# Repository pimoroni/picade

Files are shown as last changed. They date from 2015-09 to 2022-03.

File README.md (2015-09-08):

Picade
======

**This repository is for the Kickstarter Picade PCB, for the newer retail Picade please see: https://github.com/pimoroni/picade-sketch**

All Picade related designs and documents.

- **eagle**: contains the Eagle files for the Picade controller
- **software**: contains the Arduino code for the Picade controller

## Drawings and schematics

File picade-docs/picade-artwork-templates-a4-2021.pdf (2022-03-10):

## 10 inch

## 8 inch

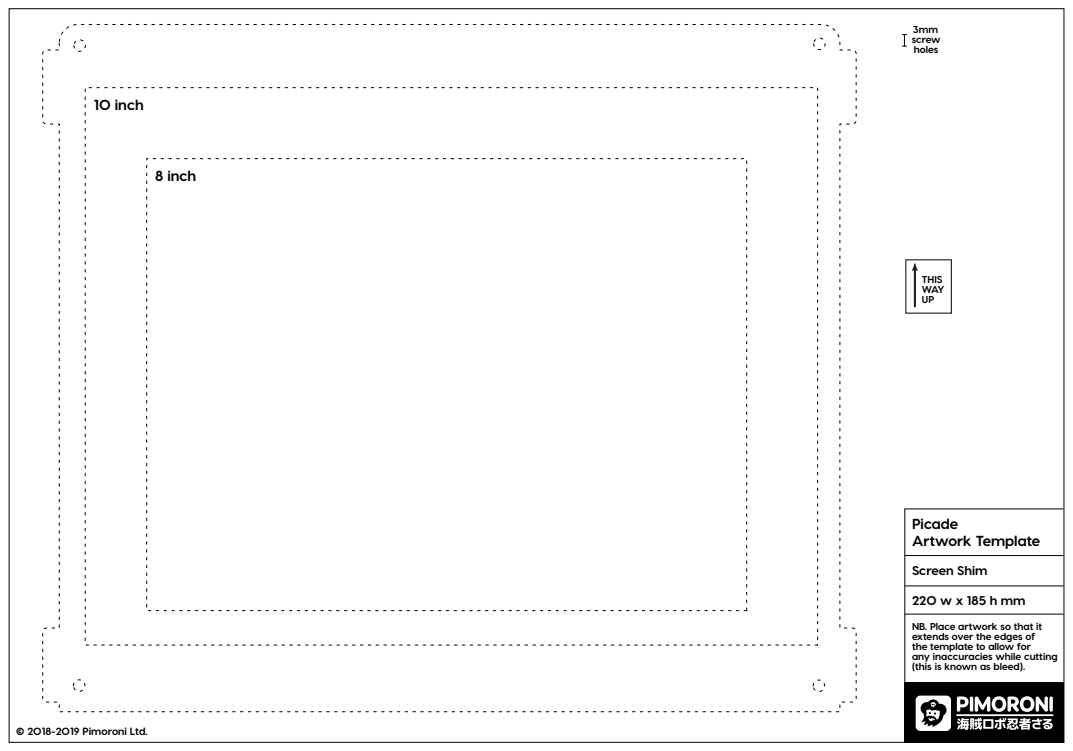
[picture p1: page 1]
Picade Artwork Template; Screen Shim; THIS WAY UP; 3mm screw holes; © 2018-2019 Pimoroni Ltd.

NB. Place artwork so that it
extends over the edges of
the template to allow for any inaccuracies while cutting
(this is known as bleed).

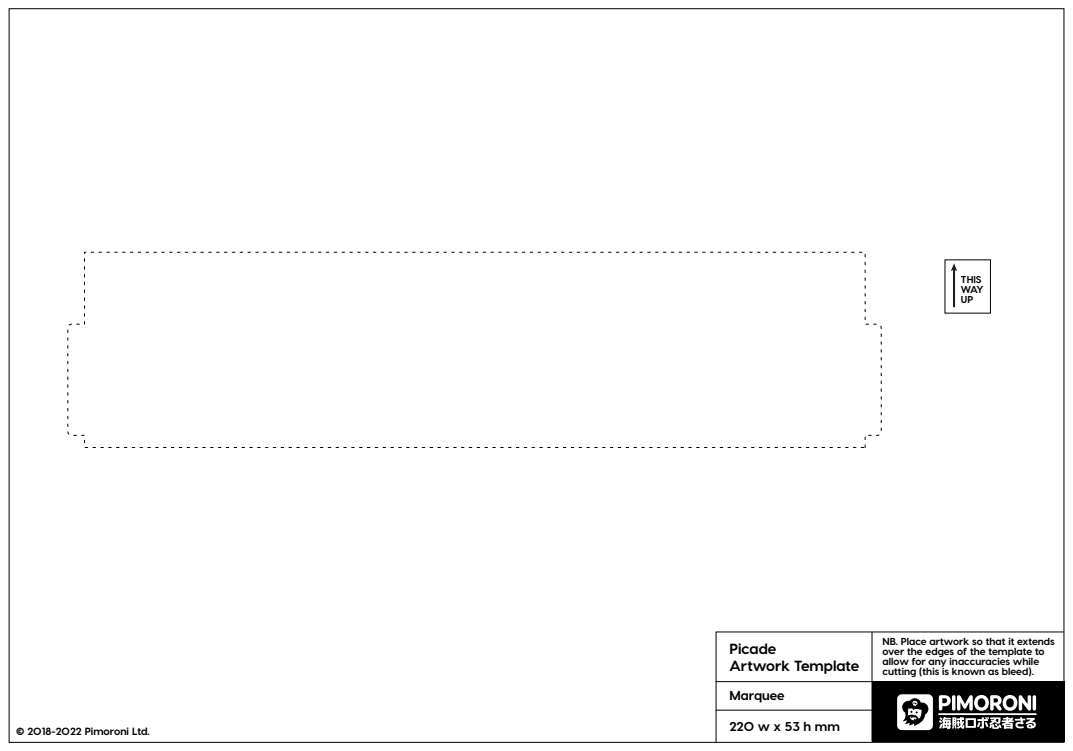
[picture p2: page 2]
THIS WAY UP; © 2018-2022 Pimoroni Ltd.

Picade Artwork Template | NB. Place artwork so that it extends over the edges of the template to allow for any inaccuracies while cutting (this is known as bleed).

Marquee

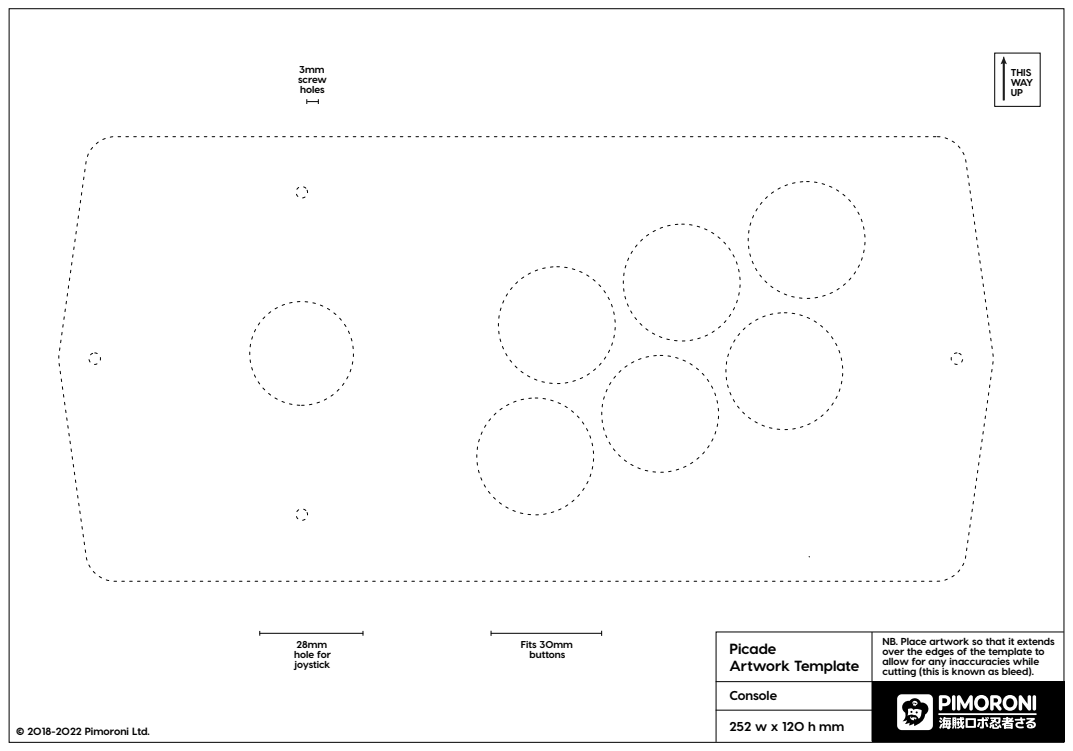
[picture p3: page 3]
THIS WAY UP; 3mm screw holes; Fits 30mm buttons; © 2018-2022 Pimoroni Ltd.

hole for joystick

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

Console

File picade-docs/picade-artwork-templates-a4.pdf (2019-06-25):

## 10 inch

## 8 inch

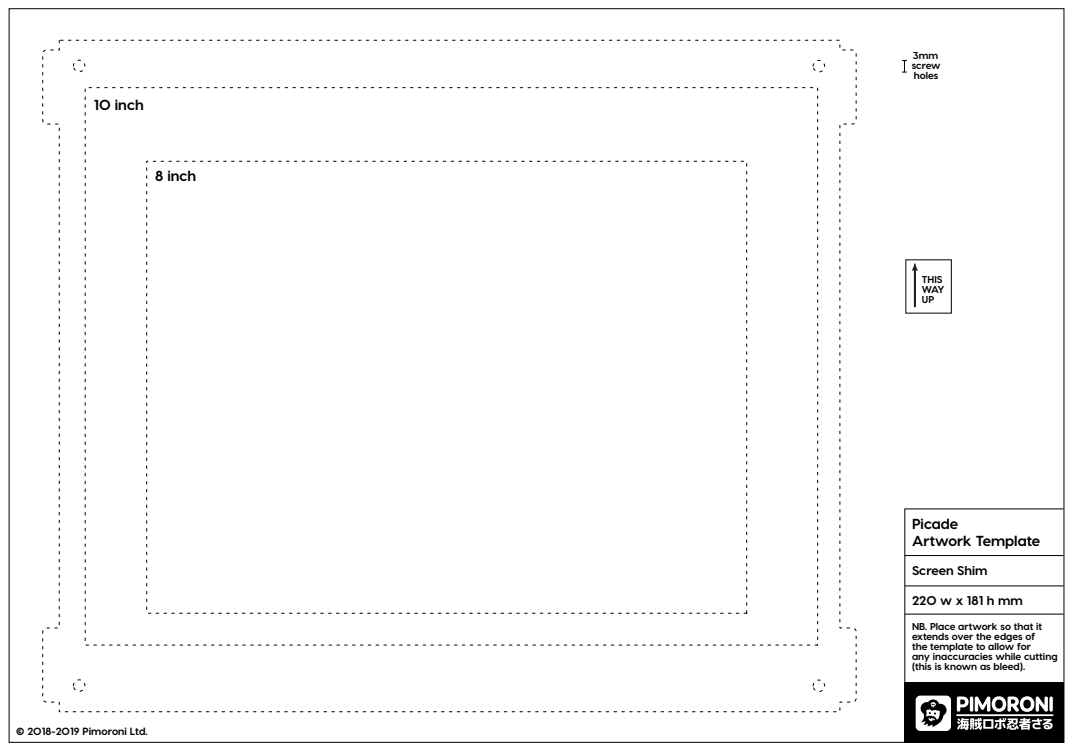
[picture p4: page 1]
Picade Artwork Template; Screen Shim; THIS WAY UP; 3mm screw holes; © 2018-2019 Pimoroni Ltd.

NB. Place artwork so that it
extends over the edges of
the template to allow for
any inaccuracies while cutting
(this is known as bleed).

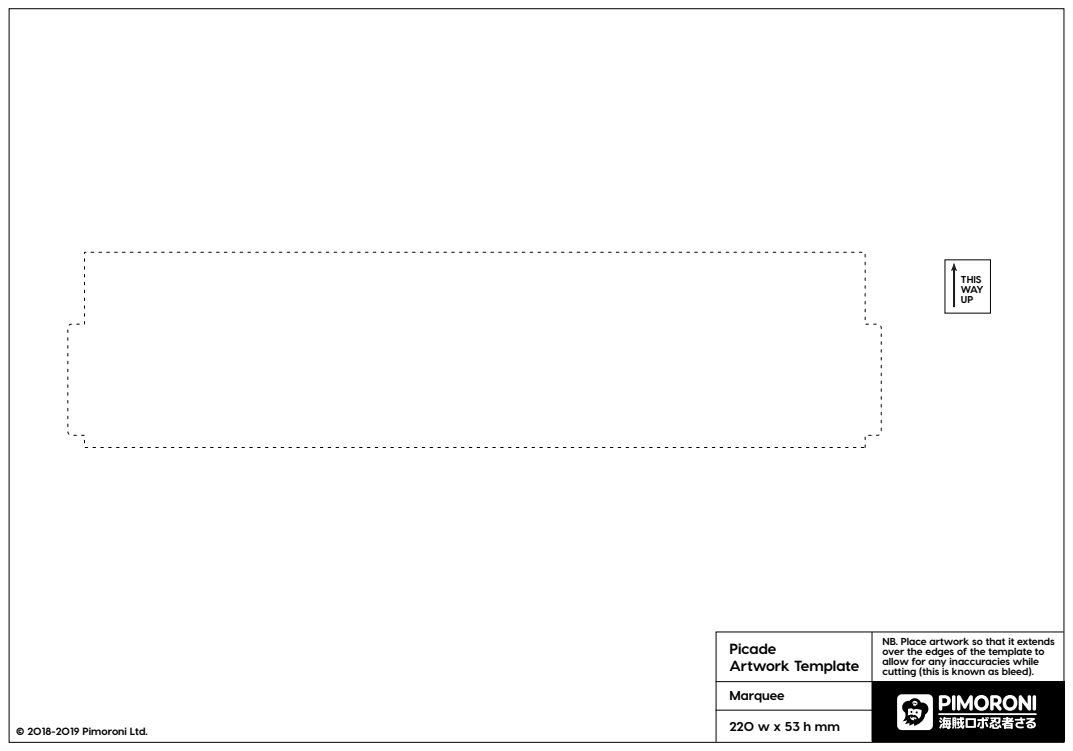
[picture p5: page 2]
THIS WAY UP

Picade Artwork Template | NB. Place artwork so that it extends over the edges of the template to allow for any inaccuracies while cutting (this is known as bleed).

Marquee

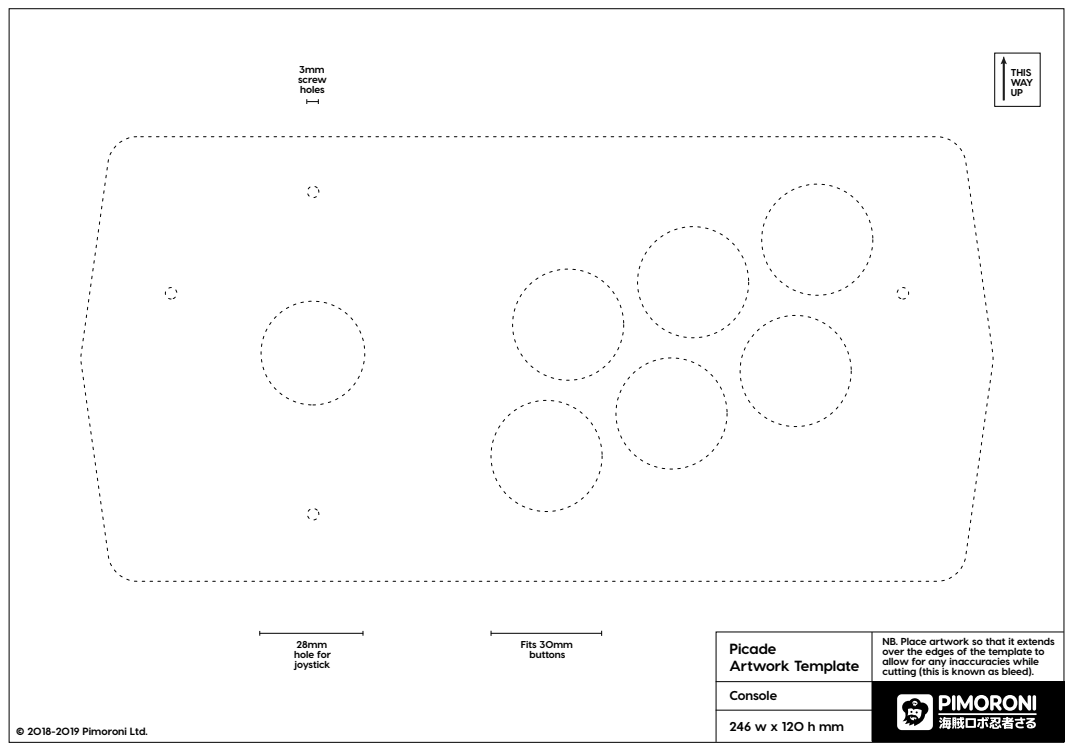
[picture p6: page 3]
THIS WAY UP; 3mm screw holes; 28mm hole for joystick; Fits 30mm buttons

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

Console

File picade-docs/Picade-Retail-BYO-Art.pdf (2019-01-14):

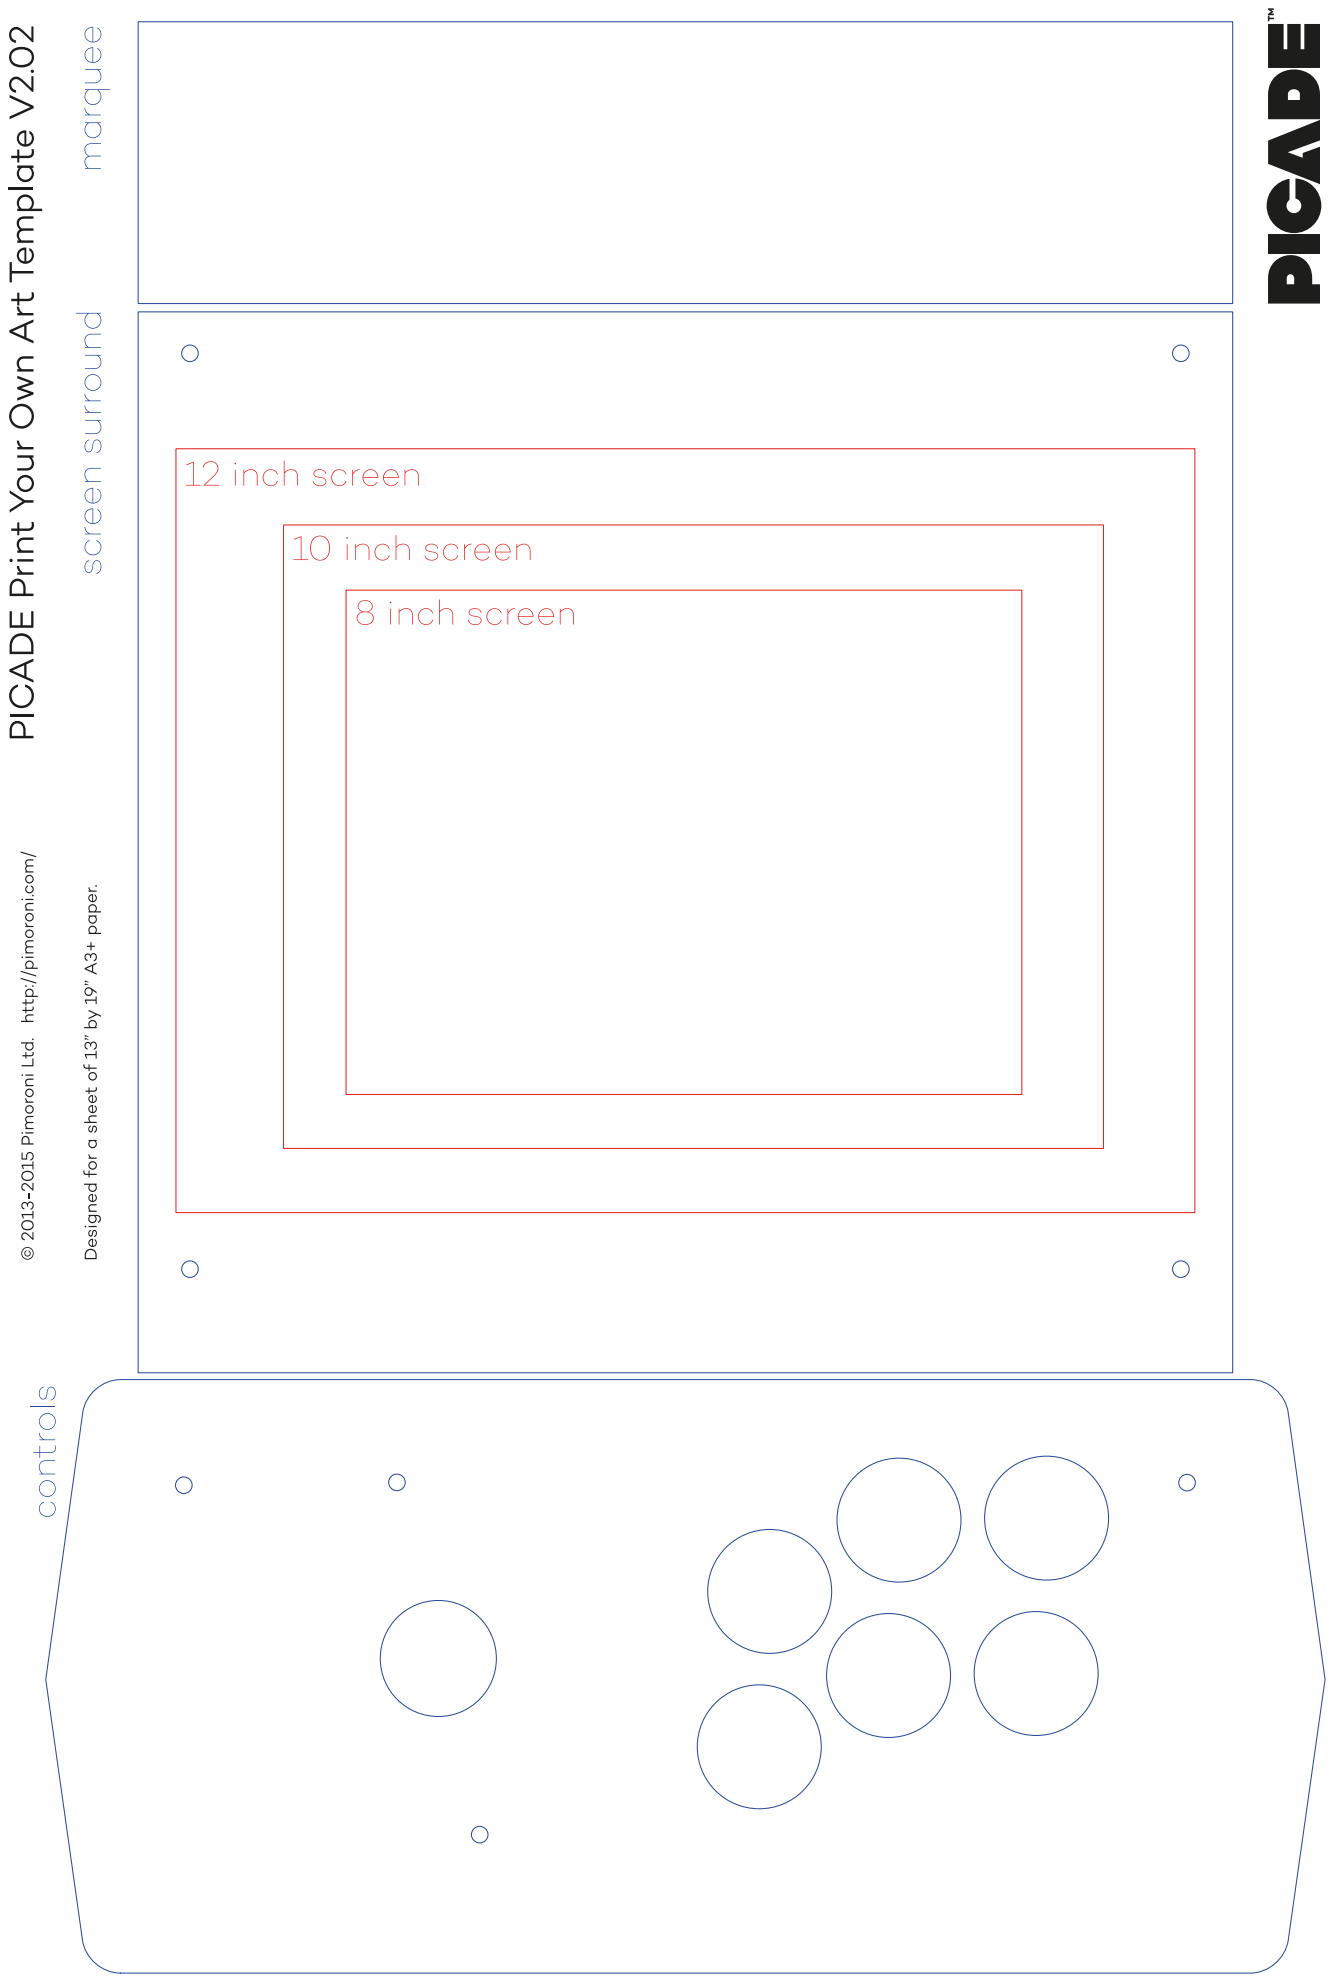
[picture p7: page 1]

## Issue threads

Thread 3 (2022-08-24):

RetroPie/Emulation Station favourites not saved using power off switch

exorsyst, 2022-08-24:
Adding game favourites to the Emulation Station UI works but if the side switch is used to shutdown the picade the fave list is not saved.  The only way for the faves to be retained for the next boot up is for ES to shutdown from within ES.

Likely mapping the shutdown script to the power button would work better than whatever it's doing at the moment.

Emulation Station v2.10.1RP
RetroPie 4.8
Rpi4
Picade 10"

Fix is to enforce Other Settings>Save Metadata "Always"

Could this be added to the install scripts to tweak that config?

Gadgetoid, 2022-08-25:
Why on earth wouldn't "Always" be the default for EmulationStation!? Really feels like a them problem :laughing:

Also I think this applies to Picade HAT here - https://github.com/pimoroni/picade-hat

Right now the power button is mapped to keycode 116 which corresponds to the "POWER" key on a keyboard. IE: it triggers a normal Linux shutdown.

We're not making any ES config tweaks in the install script at the moment, but it's not impossible. I suspect the Picade software could do with a thorough tire kicking.

In the interim this is probably something we should document in the setup instructions. @helgibbons is that something you can change?

helgibbons, 2022-08-25:
Done! https://learn.pimoroni.com/article/assembling-your-picade#troubleshooting

helgibbons, 2022-08-25:
Done! https://learn.pimoroni.com/article/assembling-your-picade#troubleshooting

helgibbons, 2022-08-25:
Done! https://learn.pimoroni.com/article/assembling-your-picade#troubleshooting

Closed 2025-01-08.

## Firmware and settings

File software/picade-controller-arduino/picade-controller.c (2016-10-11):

typedef struct
{
  char key;        // which keycode to emit when input is pressed
  int  port;       // which port is this input on? 0 = PORTB, 1 = PORTF, 2 = PORTD
  char mask;       // bitmask for the input on the port
  boolean pressed; // is this input current pressed?
} input;

// PICADE: Switch to PCB Mappings
// Ignore GPIO for Mini
//-------------------------------------------------------------------
//          /      U                 Button       | GPIO    \
//         /                     1     2     3    |   1      \
// Start  |    L   O   R                          |           |  Esc
//         \                     4     5     6    |   2      /
//          \      D                                        /
//-------------------------------------------------------------------
//           |  Select                              Enter  |


input inputs[] = {
  // 0 is PORTB
  // 1 is PORTF
  // 2 is PORTD
  // 3 is PORTC

  /* Joystick UDLR on Port B-0123 */
  { KEY_UP_ARROW,      0, B00000001, 0 },
  { KEY_DOWN_ARROW,    0, B00000010, 0 },
  { KEY_LEFT_ARROW,    0, B00000100, 0 },
  { KEY_RIGHT_ARROW,   0, B00001000, 0 },

  /* Buttons 123456 on Port F-01-4567 */
  { KEY_LEFT_CTRL,     1, B10000000, 0 }, // Button 1
  { KEY_LEFT_ALT,      1, B01000000, 0 }, // Button 2
  { ' ',               1, B00100000, 0 }, // Button 3
  { KEY_LEFT_SHIFT,    1, B00010000, 0 }, // Button 4
  { 'z',               1, B00000010, 0 }, // Button 5
  { 'x',               1, B00000001, 0 }, // Button 6
  
  /* GPIO 12/Maxi Buttons 78 on Port D-67 */
  { 'c',               2, B01000000, 0 }, // GPIO 1 / Button 7
  { 'v',               2, B10000000, 0 }, // GPIO 2 / Button 8

  /* GPIO 3456 on Port B-456 C-6 */
  { ' ',               0, B00010000, 0 }, // GPIO 3
  { ' ',               0, B00100000, 0 }, // GPIO 4
  { ' ',               0, B01000000, 0 }, // GPIO 5
  { ' ',               3, B01000000, 0 }, // GPIO 6

  /* Front/Side Buttons on Port D-0123 */
  { '1',               2, B00000001, 0 }, // 1UP Start
  { '5',               2, B00000010, 0 }, // 1UP Select/Coin
  { KEY_RETURN,        2, B00000100, 0 }, // Enter
  { KEY_ESC,           2, B00001000, 0 }  // Esc

};

// PICADE: Default Mappings
// Ignore GPIO for Mini
//-------------------------------------------------------------------
//          /      Up                Button       | GPIO    \
//         /                  LCtrl   LAlt   Spa  |   C      \
//   1    |    Le  O   Ri                         |           |  Esc
//         \                  LShft    Z      X   |   V      /
//          \      Do                                       /
//-------------------------------------------------------------------
//           |    5                                 Enter  |

// PICADE: Default Mappings
// Raw Key Codes
//-------------------------------------------------------------------
//          /     273                Button       | GPIO    \
//         /                   306     308    32  |   99     \
//  49    |   276  O   275                        |           |  27
//         \                   304     122   120  |  118     /
//          \     274                                       /
//-------------------------------------------------------------------
//           |    53                                13     |

void setup() {
  /*
    Setup the ports to be inputs will pullup resistors enabled
  */
  DDRB = DDRD = DDRF = B00000000; // set ports B, D, F to be inputs
  PORTB = PORTD = B11111111; // set the pullup resistors on ports B, D
  PORTC = B01000000; // set the pullup resistors on port C
  PORTF = B11110011; // set the pullup resistors on port F
}

void loop() {
  /*
    Check the state of each input, if it has changed then output the corresponding keypress
  */
  boolean changed = false;  // has any input changed?
  char pinStates[4] = {PINB, PINF, PIND, PINC}; // read the current port states and store in 0, 1, 2 indexed array to match our port ids above

  // loop through each input
  for(int i = 0; i < sizeof(inputs) / sizeof(input); i++)
  {
    // test for current state of this input
    boolean test = ~pinStates[inputs[i].port] & inputs[i].mask;

    if(test != inputs[i].pressed) // has this input changed state since the last time we checked?
    {
      changed = true; // something changed, we should remember that
      inputs[i].pressed = test; // update our state map so we know what's happening with this key in future

      if(test) // send the key press or release event
        Keyboard.press(inputs[i].key);
      else
        Keyboard.release(inputs[i].key);
    }
  }

  if(changed) // if an input changed we'll add a small delay to avoid "bouncing" of the input
    delay(20);
}

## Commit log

2013-05-13 Initial commit with Eagle files
    [picade.brd, picade.sch]
2013-09-18 Final Picade PCB layout
    [picade.brd, picade.sch]
2013-09-18 Renamed PCB folder
    [picade.brd, picade.sch]
2013-09-22 Renamed PCB folder and remove eagle.epf
    [picade.brd, picade.sch]
2013-09-22 Renamed controlled arduino source
2013-09-28 Renamed eagle folder
    [picade.brd, picade.sch]
2013-09-28 Switched to struct to store input information
2013-11-12 Adding more button mappins
2013-11-13 Button mapping changed and figlet art added. Debounce reduced.
    The mappings for the buttons and ports have been changed, extended and
    then labelled.
    Figlet art has been added to show the default mappings.
    The debounce has been reduced from 50ms to 20ms.
2013-11-13 Enter and Esc key mappings have been swapped.
    Enter and Esc key mappings have been swapped.
    [picade-controller.c]
2013-11-14 Text error fixed
    Some bum text was removed from a line. Bad keyboard. No Biscuit.
    [picade-controller.c]
2013-11-21 Assembly Instructions PDF Added
    The first version of the assembly instructions for the Picade,
    detailing how the kit fits together.
2013-11-22 Arduino ports remapped to the correct pins
    Arduino ports have been remapped as an error was made in the GPIO pin
    mappings.
    GPIO Pin 6 is now usable and GPIO pins 1 and 2 map to c and v keys as
    intended.
    [picade-controller.c]
2013-11-22 Esc and Enter keys reunited with their correct labels.
    Esc and Enter keys reunited with their correct labels.
    [picade-controller.c]
2014-04-17 v2.00
    Production revision of the Picade controller board with matrix scanned
    inputs, new amplifier with I2C volume control, and extra audio
    filtering.
    [picade.brd, picade.sch]
2014-04-17 Re-routed some inputs to tidy up.
    [picade.brd]
2014-04-17 Minor aesthetic changes
    [picade.brd]
2014-06-20 Picade retail board V2.01
    [picade.brd, picade.sch]
2014-07-15 Prior to amplifier change
    [picade.brd, picade.sch]
2014-07-25 v1.02
    Changed amp to allow for up/down volume control. Better USB signal
    routing. Pull-up on MODESHIFT
    [picade.brd, picade.sch]
2014-07-25 Moved stop layer glyphs to bPlace
    [picade.brd]
2014-09-16 Moved "E" in line in logo
    [picade.brd]
2014-11-03 Production candidate
    [picade.brd, picade.sch]
2015-05-27 New layout - pending silkage!
    [picade.brd, picade.sch]
2015-05-28 Added USB shield decoupling
    [picade.brd, picade.sch]
2015-05-28 Minor tweaks
    [picade.brd, picade.sch]
2015-05-28 Add art to PCB
    [picade.brd]
2015-05-28 Moved vias and stuff to avoid new silk
    [picade.brd, picade.sch]
2015-06-30 Update art to be awesomerer.
    [picade.brd]
2015-06-30 Fix slight silk positioning error.
    [picade.brd]
2015-08-16 Update BRD slightly and add templates for artwork on Picade Retail unit.
    [picade.brd]
